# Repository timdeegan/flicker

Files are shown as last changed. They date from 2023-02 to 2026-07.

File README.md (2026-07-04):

# Lighting flicker meter

This device measures the amount and speed of flicker in light sources and screens, using a phototransistor to measure the light and a Raspberry Pi Pico for signal processing.  It was designed to be cheap (less than £10 for parts in bulk, probably more like £30 to build just one) while still accurate enough to evaluate screens and lighting for those who are sensitive to flickering light.  (For information about the effects of flickering light, see e.g. [Lehman and Wilkins, 2014](https://visualstress.info/2014-220.pdf).)

## Circuit board
The PCB is a simple 2-layer layout, easily within the cheapest tier of JLCPCB or other manufacturers.  The KiCAD files are in the [pcb](pcb/) directory, along with all the output files needed to order your own PCBs.

There are only four things to solder on:
 * Raspberry Pi Pico.  This is surface-mounted on the PCB but the connections are big enough that it's quite doable by hand. I found it helped to use some 0.1" header pins to hold one side in the right place while soldering the other side.
 * 680Ω through-hole resistor.
 * AD5220BNZ10 digital potentiometer.  This costs more than the Raspberry Pi, but is rated for the current and is a through-hole part for easy soldering.  The marking on the PCB shows which way round to mount it.
 * SFH300 phototransistor.  This must also be soldered the right way round (the flat side should match the marking on the PCB) and at the right height so it's just above the PCB when the leads are bent over.

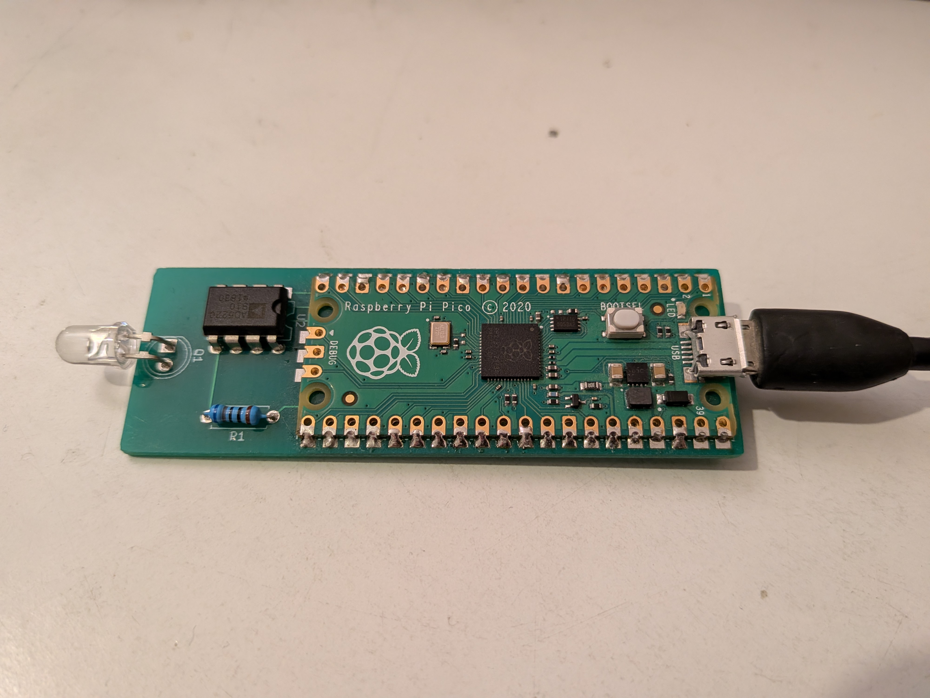
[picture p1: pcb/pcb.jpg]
The assembled PCB


## Case
The 3D model for the case is in [case/case.3mf](case/case.3mf).  I printed mine in PETG at 0.15mm "quality" on a Prusa i3 MK3S printer.

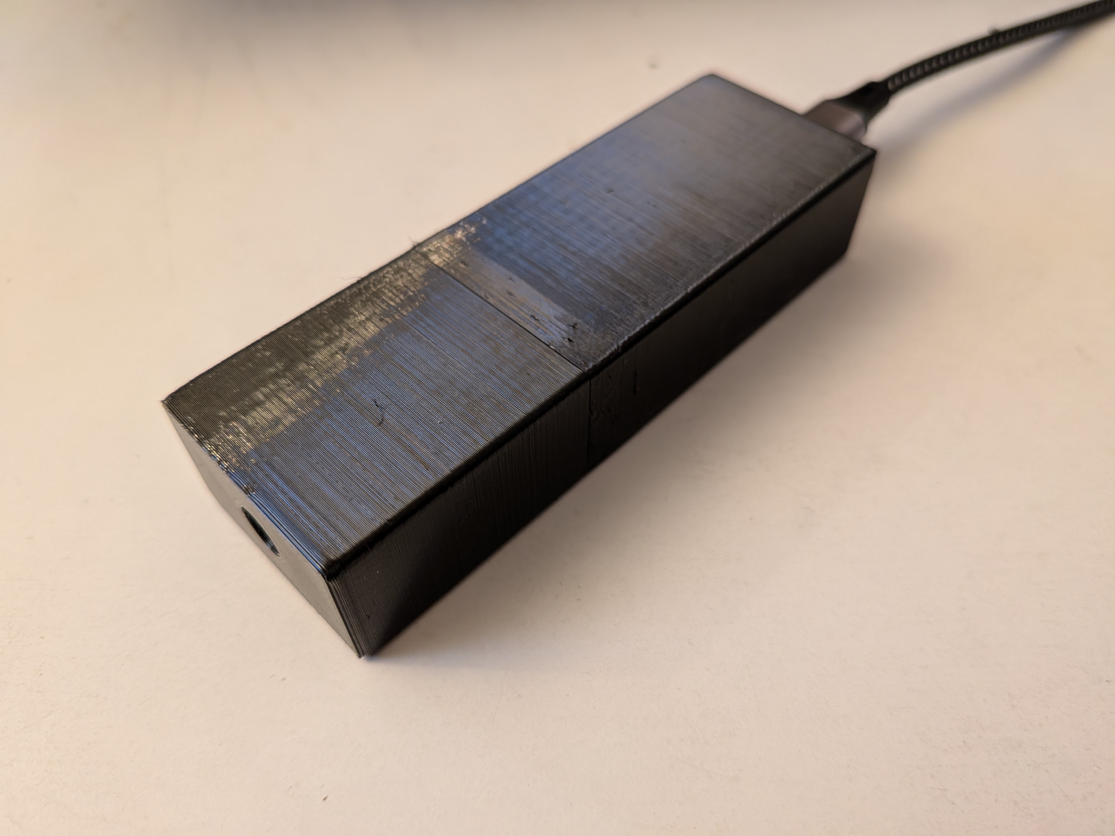
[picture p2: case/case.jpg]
The flicker meter in its case


## Firmware
The firmware that runs on the Pico is in [firmware/flicker-v1.0.uf2](firmware/flicker-v1.0.uf2).

### Installing the firmware
First connect the board by USB while holding the BOOTSEL button, which makes it appear as a USB-attached drive.  Then copy the .uf2 file to that drive.

### Building your own firmware
The firmware source is in the [firmware](firmware) directory.  If you want to build it yourself, you will need the [Raspberry Pi Pico SDK](https://github.com/raspberrypi/pico-sdk).  Once you have the SDK installed, you should be able to build the firmware using the Visual Studio Code extension as documented in the SDK.

## How to use
The flicker meter appears as a USB serial device.
* On Windows you can use [PuTTY](https://www.chiark.greenend.org.uk/~sgtatham/putty/latest.html).  Set the connection type to "Serial", the serial line to "COM3" (or check in Device Manager to see what COM number appears when you plug in the meter) and the speed to 115200.
* On Android you can use a serial terminal app such as [Serial USB Terminal](https://play.google.com/store/apps/details?id=de.kai_morich.serial_usb_terminal&hl=en_GB&pli=1).

Point the sensor at the light you want to measure.  It's usualy best to get quite close to the light it you can, unless you see a warning about it being too bright.  The measurements appear on the serial output, along with graphs of the frequency and waveform.  The graphs work best with a monospaced font and a window at least 80 characters wide.

E.g. measuring a CFL lightbulb:

```
AGC: 66/127
--------------------------------------------------------------------------------
                  *
                 * *
                 * *
                 * *
                *  *
                *   *
                *   *
                *   *
               *    *
               *    *
               *    *
              *      *
              *      *
              *      *
              *      *  *
********     *       *  ***
*       *    *        * * *
*        ****         * * * *
                       *  ** * ***                                             *
                           * ** ************************************************
--------------------------------------------------------------------------------
FFT: peak at 100.105042Hz
FFT: peak magnitude 376468.687500
--------------------------------------------------------------------------------
          *********************                    *****************
       *******           ************           *********     **************
*********                        *********** *****                      ********
  ****                                   ******                                *

--------------------------------------------------------------------------------
Raw samples: 19ms, 10% flicker.
```

The important numbers there are `10% flicker` (the amount by which the brightness varies over one cycle of the flickering) and `100Hz` (how fast it is flickering, in this case twice the 50Hz mains electricity frequency).

By contrast, a mobile phone screen using PWM for brightness control shows a faster but much deeper flicker:
```
AGC: 127/127 (TOO DARK)
--------------------------------------------------------------------------------
                          *
                          *
                          *
                          **     *
                          **     *
                          **     *
                          **     *   *
                         * *    **   *
                         * *    **   *
                         * *    **  **
                         * *    **  ** *
                         * *    **  ** **
                         * *    **  ** **
                         * *    **  ** **
                         * *    **  ** ****
                        *  *    **  ** ****
                        *   *   **  ** ****
                        *   *   * * ** *****
         ************   *   *   * * *  *** *  ****                             *
*********            ****    ****  ***** ***************************************
--------------------------------------------------------------------------------
FFT: peak at 239.751190Hz
FFT: peak magnitude 165692.468750
--------------------------------------------------------------------------------
**************************        *******************************         ******
                      ****        ********************************        ******
                         **      **                              *       **
                          *      *                               **      *
                          *      *                                *      *
                          *      *                                *      *
                          *     **                                *     **
                          **    *                                 **    *
                           *    *                                  *    *
                           *    *                                  *    *
                           *    *                                  *    *
                           **  **                                  **  **
                            *  *                                    *  *
                            ****                                    ****
                            ****                                    ****

--------------------------------------------------------------------------------
Raw samples: 8ms, 58% flicker.
```

## Limitations
It doesn't handle very bright or very dark sources, though it will warn about them being too bright or dark.  It tends to report flicker of >60KHz when in total darkness, which I assume is noise from the Pi Pico.

The phototransistor circuit is rather simple, based on my limited knowledge at the time, and the brightness compensation is a bit clunky.  I would like to redesign it at some point with a proper variable-gain amplifier and an antialiasing filter.

I haven't tried calibrating this meter or comparing it to a properly calibrated one.  Calibrated meters are rather expensive, which is why I built this in the first place.  If you have access to proper calibration equpment and would like to test one of these meters, get in touch!

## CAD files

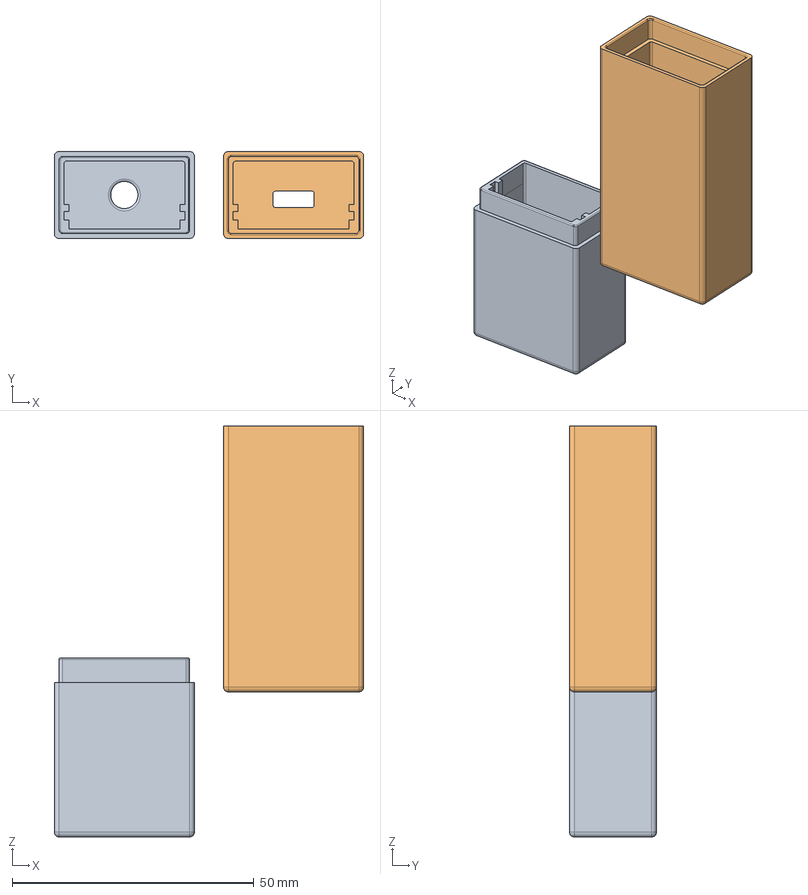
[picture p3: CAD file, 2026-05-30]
case/case.step
64.0 x 18.0 x 85.0 mm

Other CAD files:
case/case.3mf

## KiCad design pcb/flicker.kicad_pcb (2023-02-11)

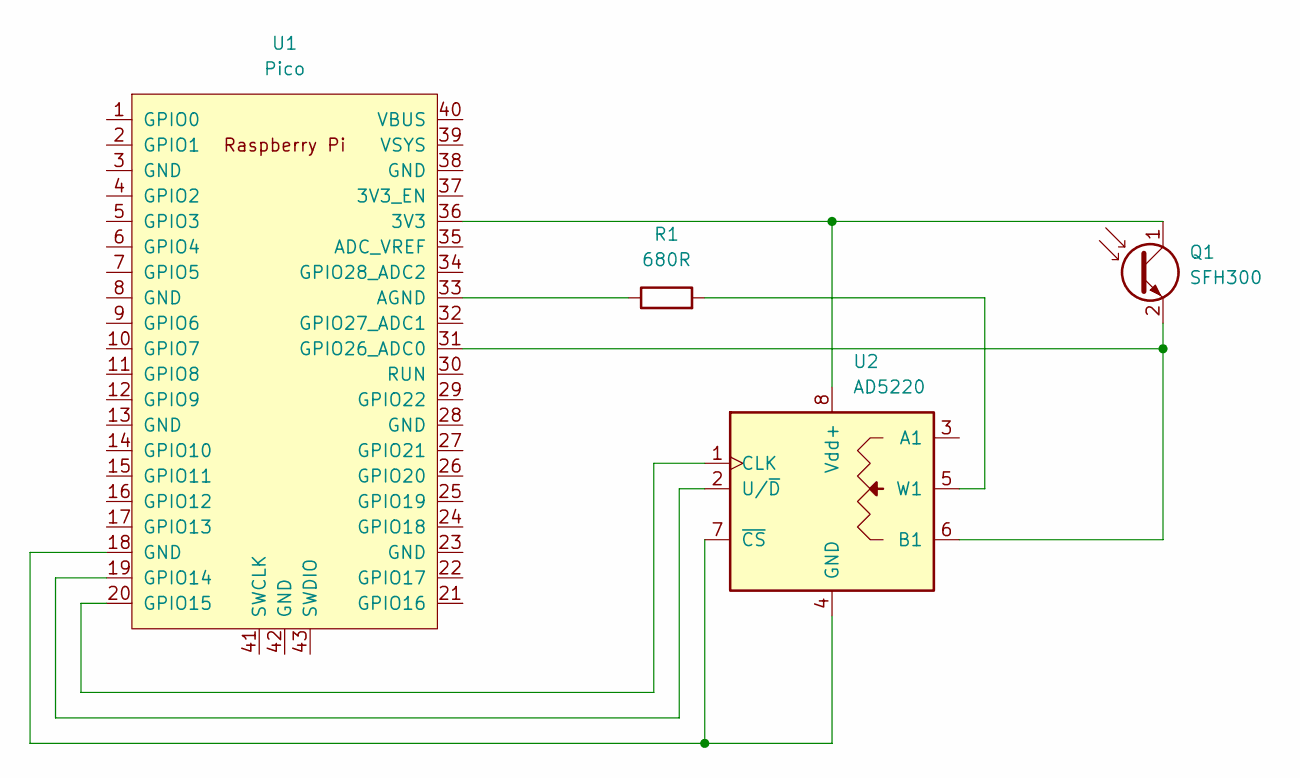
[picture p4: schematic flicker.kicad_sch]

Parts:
Q1: SFH300; LED_D5.0mm_Clear
R1: 680R; R_Axial_DIN0207_L6.3mm_D2.5mm_P7.62mm_Horizontal
U1: Pico; RPi_Pico_SMD_TH
U2: AD5220; DIP-8_W7.62mm

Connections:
unnamed: R1.2, U2.5 (W1)
unnamed: U1.18 (GND), U2.4 (GND), U2.7 (~CS)
unnamed: U1.19 (GPIO14), U2.2 (U/~D)
unnamed: R1.1, U1.33 (AGND)
unnamed: U1.20 (GPIO15), U2.1 (CLK)
unnamed: Q1.2 (E), U1.31 (GPIO26_ADC0), U2.6 (B1)
unnamed: Q1.1 (C), U1.36 (3V3), U2.8 (Vdd+)

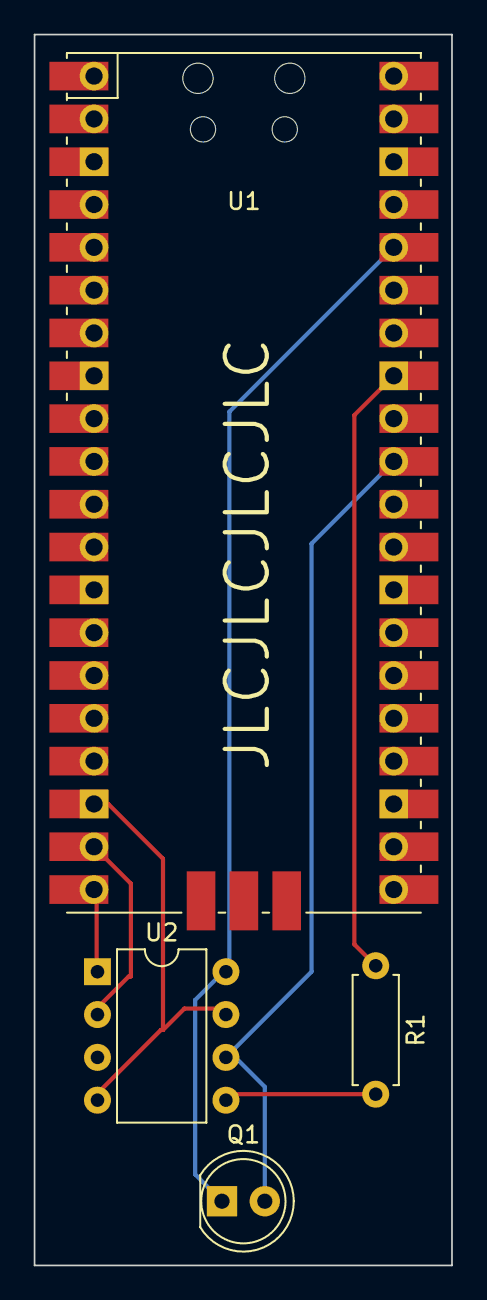
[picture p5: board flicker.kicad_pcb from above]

Board: 2 copper layers, 24.8 x 73.0 mm, 4 parts (0 on the bottom side), 7 nets.

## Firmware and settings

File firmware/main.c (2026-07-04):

#include <math.h>
#include <stdbool.h>
#include <stdint.h>
#include <stdio.h>

#include "hardware/gpio.h"

#include "pico/stdlib.h"
#include "pico/binary_info.h"

#include "agc.h"
#include "assertions.h"
#include "dsp.h"
#include "fft.h"
#include "graph.h"
#include "pins.h"
#include "sample.h"

/* The phototransistor is (just) able to pick up 110kHz
 * flicker, so we need to sample at least twice as fast.
 * The pico can go to 500kHz but we don't have room to
 * process that much data. */
#define SAMPLE_RATE 250000.0

/* Sample count is limited by our FFT implementation.
 * It uses 8 bytes per sample and only works on powers of two,
 * so use 128kB just for that, and everything else fits in the
 * other half of memory.  That give us 1/16th of a second
 * at our chosen sample rate, i.e. 6.25 cycles of 100Hz. */
#define SAMPLE_COUNT (16u * 1024u)

/* FFT buckets: the FFT produces twice as many but
 * everything above this is just aliasing. */
#define FREQ_COUNT ((SAMPLE_COUNT / 2u) + 1u)
#define HZ_PER_BUCKET ((SAMPLE_RATE / 2) / (FREQ_COUNT - 1))
static inline unsigned int to_bucket(float hz)
{
    return roundf(hz / HZ_PER_BUCKET);
}
static inline float to_frequency(float bucket)
{
    return HZ_PER_BUCKET * bucket;
}

/* FFT bucket above which we ignore things because
 * of noise.  Ideally we could go all the way to
 * FREQ_COUNT, but in practice we get a lot of noise
 * below that.  I can see noise at 130kHz on the 3V3 line
 * wich ought to show up in our samples aliased at 120kHz;
 * in our FFTs we see noise centred at about 90kHz too.
 * For now, limit to 1/4 the sample freq (i.e. 62.5kHz).
 * It would be nice to make some hardware improvements
 * here because I know the phototransistor can pick up
 * 3% flicker at 75kHz. */
 #define FREQ_LIMIT (FREQ_COUNT / 2)

/* Raw 12-bit samples from the ADC. */
static uint16_t samples[SAMPLE_COUNT];

/* FFT calculation space.
 * We convert cartesian to polar coordinates in place to save space.
 * I can't think of a nice way of doing that without turning off
 * the aliasing rules, but we have turned them off, so that's OK. */
static struct {
    union {
        float real[SAMPLE_COUNT];
        float magnitude[FREQ_COUNT];
    };
    union {
        float imag[SAMPLE_COUNT];
        float phase[FREQ_COUNT];
    };
} f;

/* Assertion failures stop the world and keep logging so
 * we can connect the serial console to debug.  */
void assertion_failure(const char *pred, const char *file, int line)
{
    while (true) {
        printf("ASSERTION FAILED at %s line %d: %s\n", file, line, pred);
        gpio_put(LED_PIN, 1);
        sleep_ms(10);
        gpio_put(LED_PIN, 0);
        sleep_ms(990);
    }
}

/* Calculate the modulation percentage of these samples. */
static int mod_percent(uint16_t *samples, unsigned int count)
{
    unsigned int max = 0, min = -1;

    for (unsigned int i = 0; i < count; i++)
    {
        float s = samples[i];
        max = (s > max) ? s : max;
        min = (s < min) ? s : min;
    }

    /* N.B. *not* (100 * (max - min) / max), as you might expect. */
    return (int) roundf(100.0 * (max - min) / (max + min));
}

/* Measure a light source and report on it.
 * Returns false on error. */
static bool measure(void)
{
    float frequency;
    unsigned int cycle, mod;

    /* Set the gain so we'll fill the ADC range. */
    agc_run(samples);

    /* Collect uint16_t samples in [0, 0xfff]. */
    sample(SAMPLE_COUNT, SAMPLE_RATE, samples);

    /* Put the AGC back in a known safe state. */
    agc_reset();

    /* Find the spectrum and the peak frequency. */
    if (!window(samples, f.real, f.imag, SAMPLE_COUNT)) {
        return false;
    }
    fft(f.real, f.imag, SAMPLE_COUNT);
    make_polar(f.real, f.imag, f.magnitude, f.phase, FREQ_COUNT);
    frequency = to_frequency(peak(f.magnitude, FREQ_LIMIT));

    /* Look at the spectrum. */
    graph_logx(f.magnitude, FREQ_LIMIT);
    printf("FFT: peak at %fHz\n", frequency);
    printf("FFT: peak magnitude %f\n",
        f.magnitude[to_bucket(frequency)]);

    /* Look at a couple of cycles of the raw samples. */
    cycle = SAMPLE_RATE / frequency;
    if (cycle > SAMPLE_COUNT / 2) {
        cycle = SAMPLE_COUNT / 2;
    }
    graph(samples + SAMPLE_COUNT / 2 - cycle, cycle * 2);
    mod = mod_percent(samples + SAMPLE_COUNT / 2 - cycle, cycle * 2);
    printf("Raw samples: %dms, %d%% flicker.\n",
           (unsigned int)(2 * cycle / SAMPLE_RATE * 1000),
           mod);

    return true;
}

int main(void)
{
    /* Debugging metadata that gets baked into the binary. */
    bi_decl(bi_program_name("flicker"));
    bi_decl(bi_program_version_string("1.0"));
    bi_decl(bi_program_description("Lighting flicker meter"));

    /* Debugging output will go to the USB console. */
    stdio_init_all();

    /* Set up the LED in case we need to signal with it. */
    gpio_init(LED_PIN);
    gpio_set_dir(LED_PIN, GPIO_OUT);
    gpio_put(LED_PIN, 1);

    /* Put the power supply in PWM mode.  This should be less
     * efficient but less noisy.  (Pico datasheet section 4.4) */
    gpio_init(SMPS_PIN);
    gpio_set_dir(SMPS_PIN, GPIO_OUT);
    gpio_put(SMPS_PIN, 1);

    /* Set up our collection machinery. */
    sample_init(PT_PIN);
    agc_init(AD5220_DIR_PIN, AD5220_CLOCK_PIN);

    gpio_put(LED_PIN, 0);

    while (1) {
        /* TODO: wait for a button press? */
        sleep_ms(2000);
        measure();
    }
}

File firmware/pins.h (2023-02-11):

#pragma once

/* These are GPIO pin numbers on the RP2040 itself.
 * The pin numbers on the Pico board are given in the comments. */

/* AD5220 digital potentiometer. */
#define AD5220_DIR_PIN 14 /* Pico 19 */
bi_decl(bi_1pin_with_name(AD5220_DIR_PIN, "AD5220 up/down"));
#define AD5220_CLOCK_PIN 15 /* Pico 20 */
bi_decl(bi_1pin_with_name(AD5220_CLOCK_PIN, "AD5220 clock"));

/* Osram SFH300 phototransistor. */
#define PT_PIN 26 /* Pico 31 */
bi_decl(bi_1pin_with_name(PT_PIN, "SFH300 phototransistor"));

/* Pico's on-board switched mode power supply. */
#define SMPS_PIN 23
bi_decl(bi_1pin_with_name(SMPS_PIN, "Pico SMPS control"));

/* Pico's on-board LED. */
#define LED_PIN 25
bi_decl(bi_1pin_with_name(LED_PIN, "Pico LED"));

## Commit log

2021-09-21 12-bit ADC sampling
2021-09-26 Start putting things together.
    Enough code to sample a light source, show the samples and the FFT.
    Still a fair bit missing, but it gets plausible results.
    [main.c]
2021-09-30 Switch to 250kHz sampling.
    Now that we interpolate frequencies we don't care about integer
    bucket widths, so use something that divides the reference clock more
    cleanly.
2021-09-30 Avoid an edge case when sampling at 500kHz.
    The hardware doesn't seem to quite match the docs here,
    but it's easy to fix by just using 0 for 500kHz. We're
    not going anywhere near that speed but it came up in testing.
    [sample.c]
2021-10-09 PIO driver for AD5220 potentiometer.
    PIO state machine to handle up/down and clock pins, and a bit of glue
    to bring it up to where we'll need it for gain control.
2021-10-09 Test for V proportional to R.
    To check that we are really controlling the AD5220 potentiometer,
    see if the sampled levels go up and down the way they should.
    This test assumes roughly constant lighting over about 100ms,
    and that the PT current is more-or-less independent of the
    applied voltage in the operating range.
2021-10-10 Account for "wiper contact" resistance.
    The AD5220 has another 40 ohms (+/- 12) of resistance
    on the wiper terminal that needs to be included in the sums.
2022-04-30 Add the first 3D-printed parts.
    Enough to hold the PT with the filter in front of it.
    [case.scad]
2022-05-01 Adjusting the PT holder for a better fit.
    [case.scad]
2023-02-09 Noise improvements, part 1.
    Switch the Pico's PSU to PWM mode, which draws more power but shifts
    the noise on the 3V3 line from ~40kHz up to ~130kHz.
    Cut our own FFT off at 62kHz, to avoid noise centred around 90kHz that
    I wasn't able to fix by throwing capacitors at it. That's half the
    Nyquist frequency, which is probably still optimistic.
    [case.stl]
2023-02-11 Swap clock and up/down pins on the AD5220
    [pins.h]
2023-02-11 First attempt at PCB layout
    [flicker.kicad_pcb, flicker.kicad_sch]
2023-02-13 Don't track Android IDE config in git
2023-02-17 UI: auto-start based on USB ID
    Filter on the Pico's UART device for now. I should change that
    to a proper VID/PID later so the app doesn't have to wake for
    every Pico ever. The Pi docs suggest filtering on the USB
    *strings* but the Android SDK only filters on ID numbers. :(
2026-05-29 Remove partial UI app and SCAD files
    These were never complete enough to be useful.
    [case.scad, case.stl]
2026-05-29 PCB: use complete part number for AD5220BNZ10
    [flicker.kicad_sch]
2026-05-30 Add the case
    [case.3mf, case.step]
2026-07-04 Update to latest Pi Pico SDK
